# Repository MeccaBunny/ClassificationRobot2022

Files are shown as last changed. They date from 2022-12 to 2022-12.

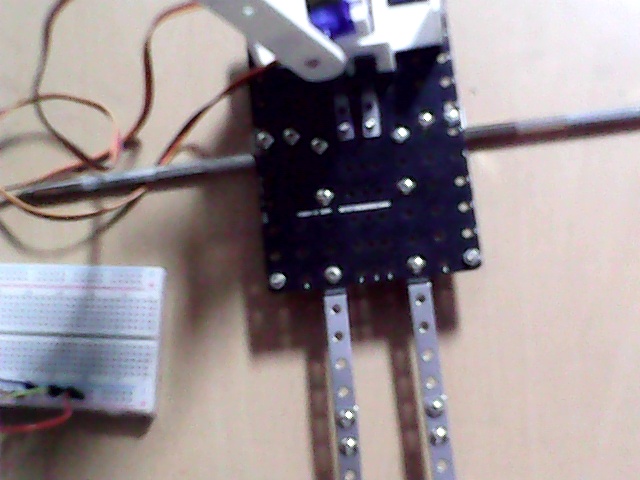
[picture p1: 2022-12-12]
robot_arm_controller/photo.jpg

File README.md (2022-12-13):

## ClassificationRobot2022

Uploaded files are located at /home/meccabunny/robot_ws/src/robot_arm_controller/robot_arm_controller/

Also yolov3.weights should be added to that directory too.

link to download yolov3.weights: https://pjreddie.com/darknet/yolo/

The environment I used to develop this robot is ubuntu 22.04. and the Open-source-software I used is ROS-humble, yolov3, opencv 4.6.0.

"robotParts" contains the stl file I used to 3d print this robot arm.

"robotArm" contains the arduino file for robot arm. <br/> <br/>

To Activate a robot,

First, Turn on 6 terminals in ubuntu. <br/> <br/>

Second, turn on arduino ise and upload the file given in robotArm.

$ arduino

Uploading the code directly will cause an error.

The reason for this error is because usb port connected to arduino cable is not authorized.

Copy and paste this command in 2nd terminal.

$ sudo chmod a+rw /dev/ttyACM0 <br/> <br/>

Third, for each terminal, turn on the ROS nodes to activate the robot arm.

To do this, copy and paste this commands to 3rd, 4th, 5th terminal.

$ ros2 run robot_arm_controller actionBuf

$ ros2 run robot_arm_controller inverse_kinematics

$ ros2 run robot_arm_controller CameraToUV  <br/> <br/>

Finally, copy and paste this command to 6th terminal.

$ cs

$ code .

Meaning of this code is that you are turning on vscode in directory "~/robot_ws/src/".

Then, run the python code, "ObjectDetectionCamera.py"

<br/>

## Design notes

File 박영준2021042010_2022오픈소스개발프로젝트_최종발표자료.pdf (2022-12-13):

# 산업용 분류로봇

## 2022오픈소스개발프로젝트

### 박영준2021042010

목차

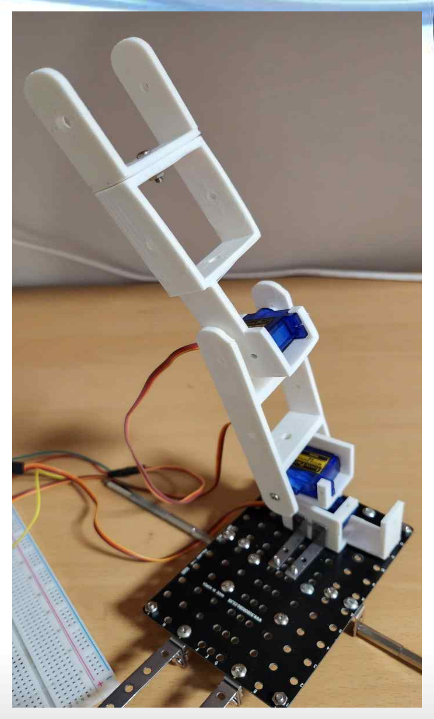
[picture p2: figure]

## - 1. 과제 제목 & 개요

## - 2. 과제 필요성

## - 3. 개발 목표

## - 4. 프로젝트 설계

## - 5. 개발 일정 & 실적

## - 6. 프로젝트 결과

## - 7. 소감 및 후속 연구 계획

# 1. 과제 제목 & 개요

# 과제명: 분류 로봇

## 산업환경에서 공장 자동화에 필수적인 분류로봇을 구현한다. 분류로봇은 카메라를 이용하여 불량한 제품을 파악하고, 로봇팔을 이용

하여 불량한 제품을 컨베이어벨트에서 제거한다. 이 프로젝트의 최종목표는 분류로봇의 시제품을 제작하는 것이다.

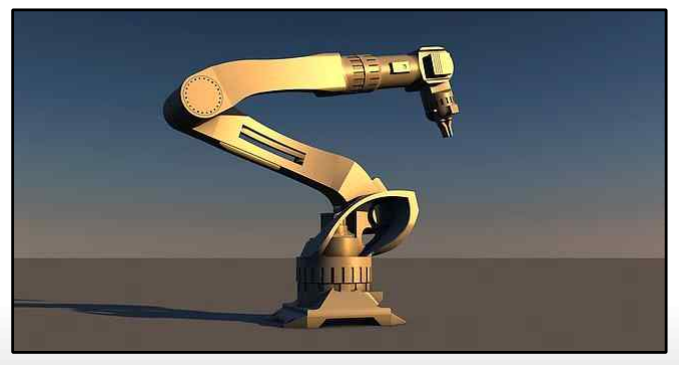
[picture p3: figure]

# 2. 과제 필요성

# 고령화시대

### - 우리나라는 현재 인구는 감소하고 있

### 지만, 고령자의 비중은 급속히 늘어나는

### 초고령사회에 들어섰다. 이러한 위기에서

### 우리나라가 그 미래를 대비하기 위헤서는

### 무인공장(스마트펙토리)을 도입하는 것은

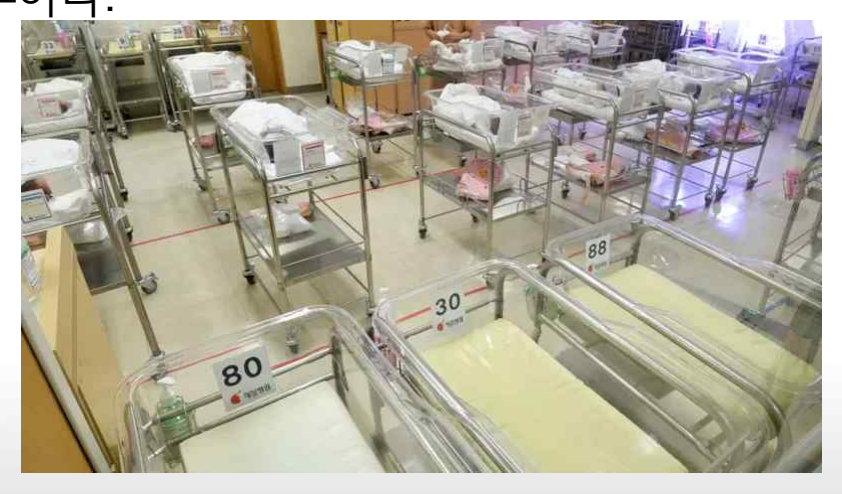
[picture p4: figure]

필수이다.

# 저렴한 로봇팔의 필요성

### - 인공지능 기술의 발달로 인하여 인간의 삶

### 의 많은 것을 자동화하는 기술이 연구되고 있

### 다. 이로 인하여 고등 정보기술 교육의 중요성

### 이 점점 높아지고 있다. 로봇을 조작하는 실습

### 으로 활용하기 좋은 기계들은, 교육에서 활용

하기에는 비싼 경우가 많다.

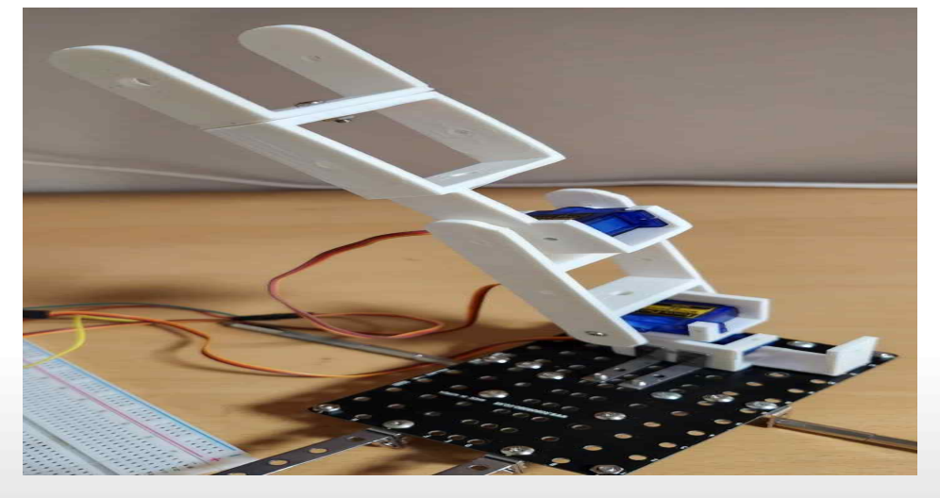
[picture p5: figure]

# 3. 개발 목표

-5000원 이하로 구현 가능한 다목적 로봇팔.

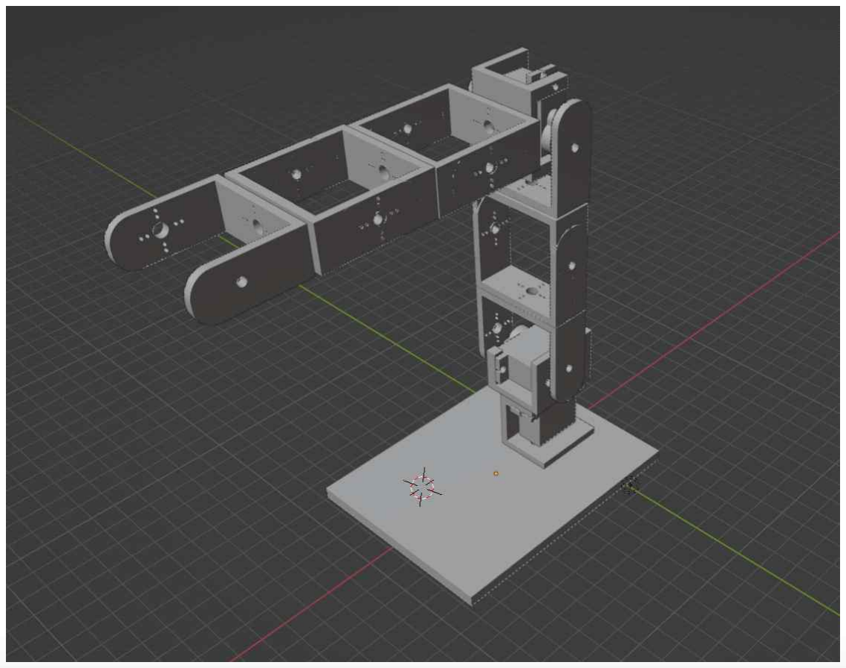
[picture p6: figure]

-YOLO를 활용한 객체인지 실습.

### -역기구학을 구현하여 로봇의 손 부분의

### X, Y, Z를 입력으로 로봇팔을 제어

# 4. 프로젝트 설계

### Classify goods using YOLO

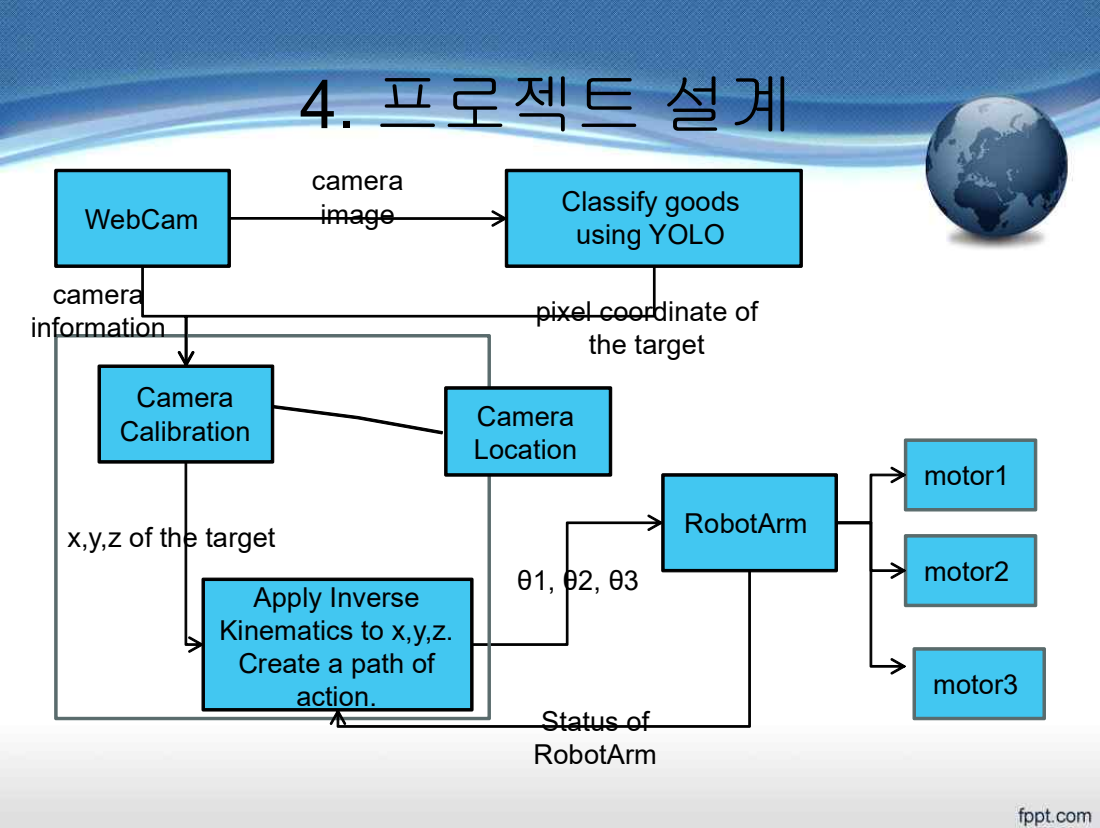
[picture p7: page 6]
WebCam; camera image; Camera Calibration; x,y,z of the target; RobotArm; motor1 motor2; Status of RobotArm; camera; information; Camera; Location; motor3

pixel coordinate of
the target

Apply Inverse Kinematics to x,y,z. Create a path of action.

# 4. 프로젝트 설계

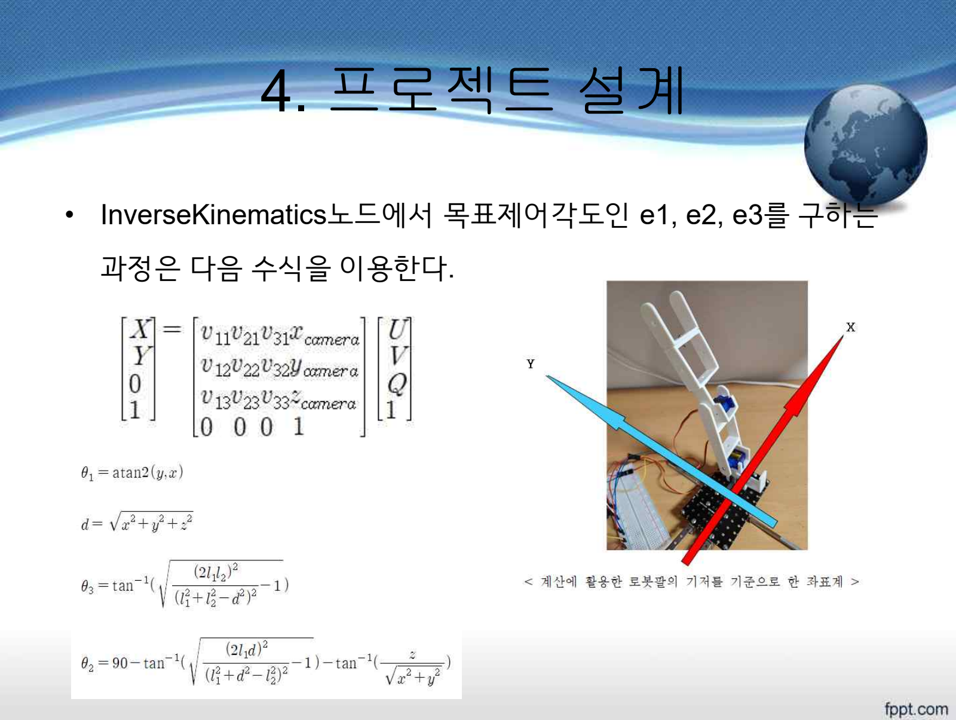
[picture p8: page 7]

## - InverseKinematics노드에서 목표제어각도인 e1, e2, e3를 구하는

과정은 다음 수식을 이용한다.

# 5. 개발 일정 & 실적

# - 1차 중간 발표까지 하드웨어를 제작. 웹캠을

보고 인간이 로봇팔을 조종하는 단계까지 제작.

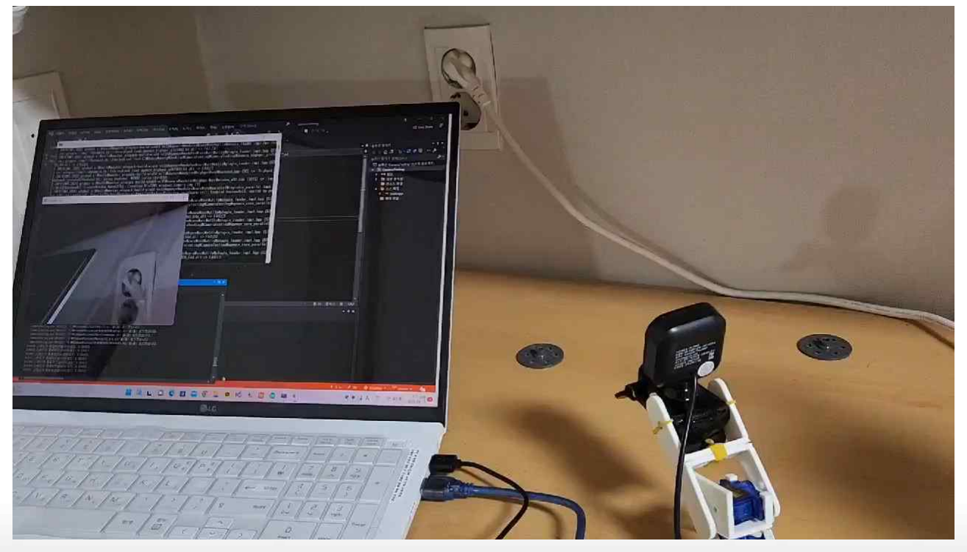
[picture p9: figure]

# 5. 개발 일정 & 실적

# - 2차 중간 발표까지 카메라와 로봇팔이 움직이는

부분에 대해서 최종제작을 하여 시제품을 발표.

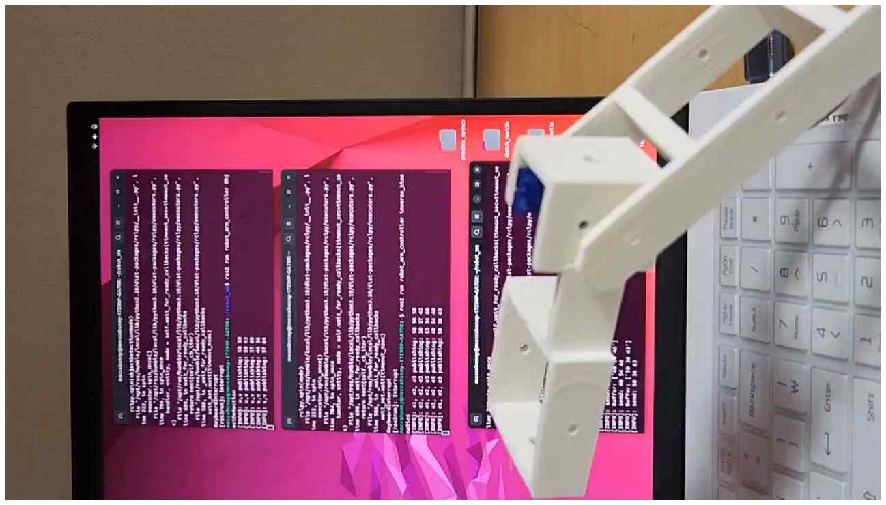
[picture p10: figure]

# 6. 프로젝트 최종 결과

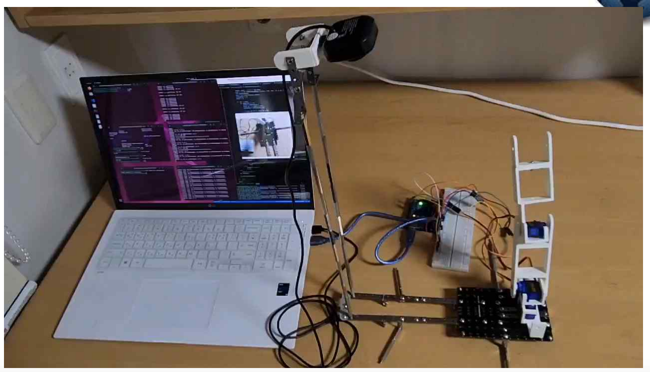
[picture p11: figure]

# 6. 프로젝트 최종 결과

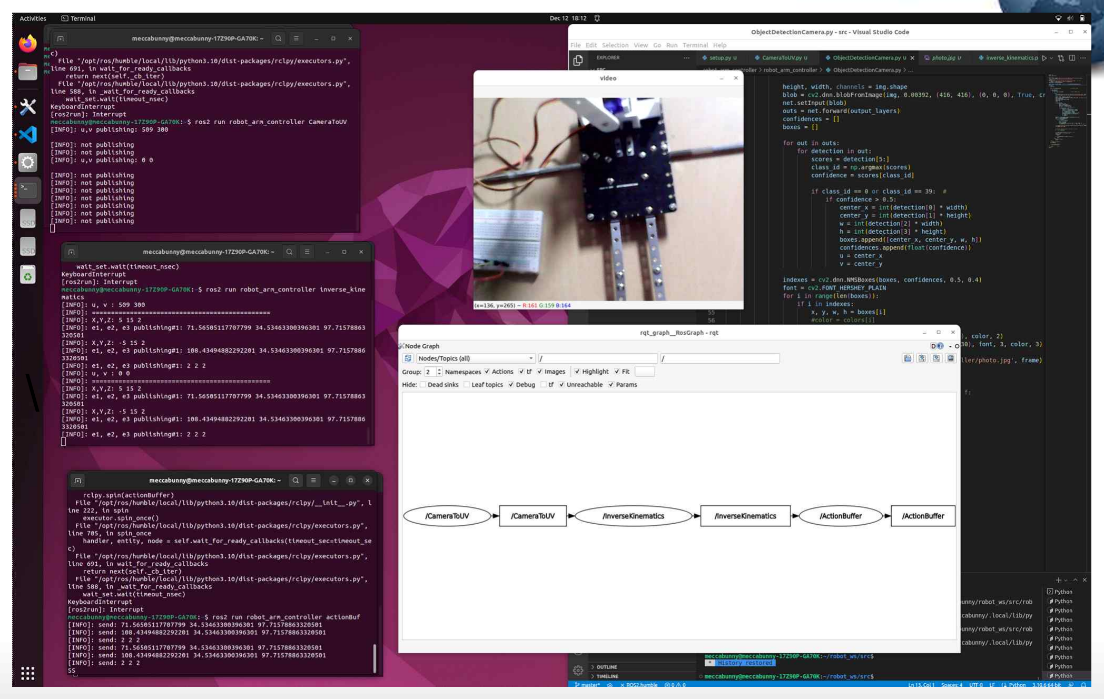
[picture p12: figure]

- \

# 6. 프로젝트 최종 결과

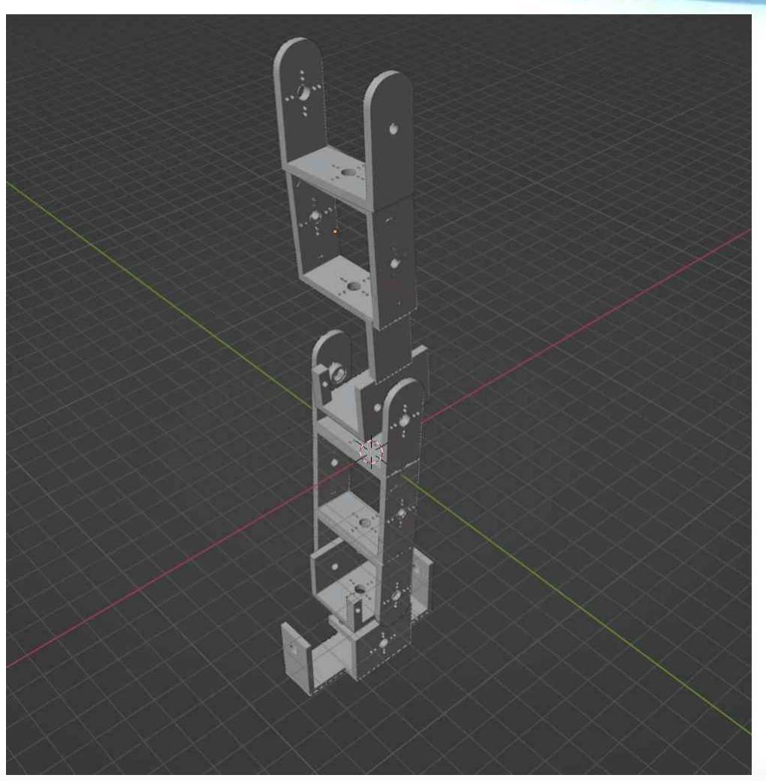
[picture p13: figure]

# 7. 소감 및 후속연구 계획

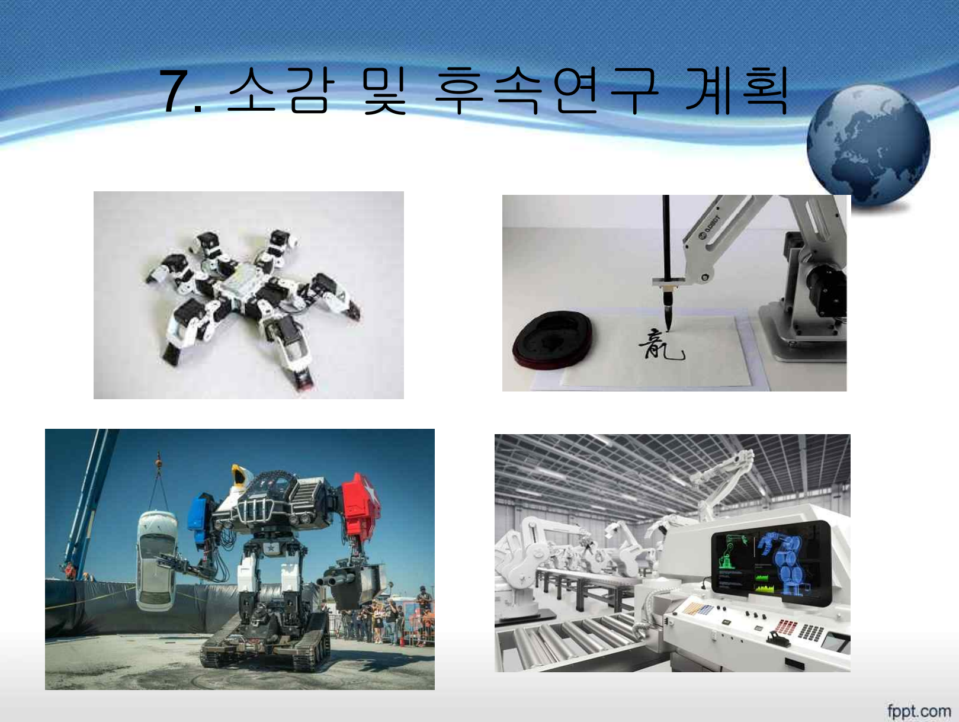
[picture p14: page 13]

# 참고자료

Ÿ과제의 필요성(초고령사회): https://www.bbc.com/korean/news-54506949

ŸSG-90 모터 브라켓 STL:https://cults3d.com/en

ŸROS-humble: https://docs.ros.org/en/humble/Installation/Ubuntu-Install-Debians.html

ŸOpenCV: https://docs.opencv.org/4.x/d9/df8/tutorial_root.html

Ÿhttps://pysource.com/2019/06/27/yolo-object-detection-using-opencv-with-python/

Ÿ표윤석, 임태훈. 『ROS 2로 시작하는 로봇 프로그래밍』. 루비페이퍼, 2021. ŸJohn J. Craig. 『Introdution to Robotics Mechanics and control』. 3

rdEdtion . Pearson Prentice Hail, 2005. Ÿ허경용. 『아두이노 Arduino 상상을 스케치하다』. 제이펍, 2014.

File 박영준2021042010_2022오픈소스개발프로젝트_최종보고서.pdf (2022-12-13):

과목명:
담당교수:
학과:
학년:
학번:
이름:

20223오픈소스개발프로젝트
기석철
지능로봇공학과
2학년
2021042010
박영준

# 20223오픈소스 개발 프로젝트

# 최종보고서

### 20223 OpenSW Development Project Final Report

목 차

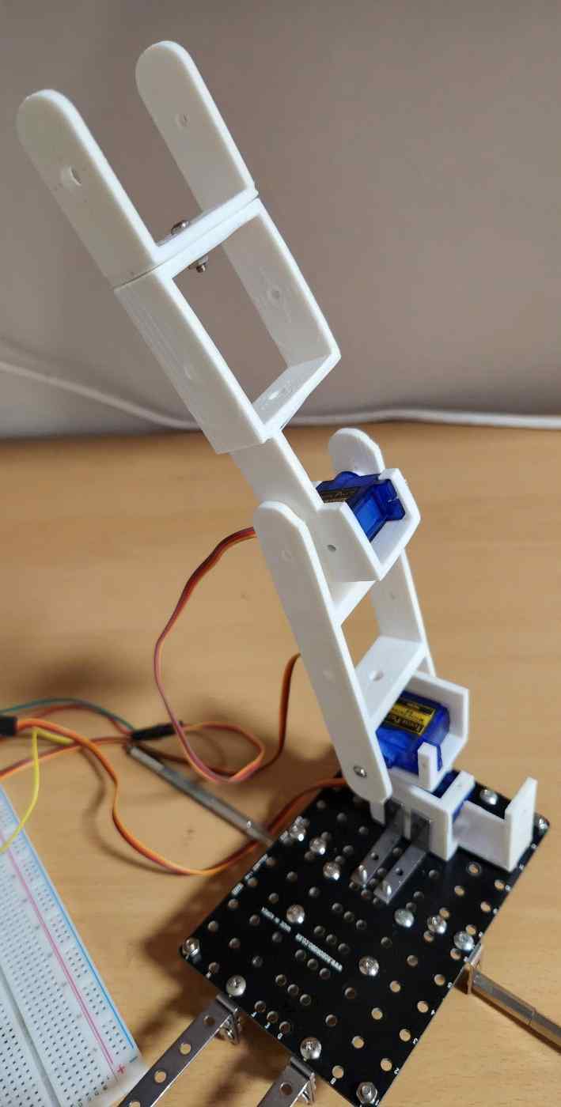
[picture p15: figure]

1. 과제 제목 & 개요
2. 과제 필요성
3. 개발 목표
4. 프로젝트 설계
-하드웨어 설계
-개발환경
-ROS 노드 연결 관계
5. 개발 일정 & 실적
-개발 일정
-1차 중간 발표
-2차 중간 발표
6. 프로젝트 결과
-최종 결과물
7. 소감 및 후속 연구 계획
-소감
-후속 연구 계획

# 산업용 분류 로봇

### Classification Robot

박영준
Park Youngjune

### 2. 과제 필요성

무인공장은 우리나라에 필수적이다. 우리나라는 현재 인구는 감소하고 있지만, 고령자의 비중은 급속히 늘어나는 초고령사회에

들어섰다. 내국인의 생산연령인구(15~64세) 구

성비는 2020년 71.5%에서 2040년 55.6%로 감

소할 것으로 보인다. 또한 미국의 계속되는 금리

인상에 의한 파장으로 물가가 치솟으면서 기업의

비용 부담이 늘어나고 소비자의 소비력이 구매력

이 감소하는 가운데 이미 경제는 여러 도전에 직

면해 있는 상황이다. 이러한 위기에서 우리나라

의 제조업이 취할 수 있는 선택지 중에는 무인공

장을 도입함으로써 인건비를 줄이는 방법이 있

다. 앞으로 미래에는 지금보다 더한 경제적인 위

기가 아주 많이 있을 것이다. 우리나라가 그 미

래를 대비하고 피해를 최소화하기 위해서는 무인

공장을 도입하는 것은 기업에 필수적이다. 저렴하게 제작 가능한 로봇팔이 필요하다. 인공지능 기술의 발달로 인하여 인간의 삶

의 많은 것을 자동화하는 기술이 연구되고 있다. 이로 인하여 고등 정보기술 교육의 중요성이 점

점 높아지고 있다. 정보기술을 이용하여 로봇을

조작하는 실습으로 활용하기 좋은 기계에는, RC

자동차, 로봇팔, 드론 등등이 있다. 그러나 이러

한 기계들은 교육에서 활용하기에는 비싼 경우가

많다. 고등 및 대학 교육에서 개인이 각각 로봇

팔을 이용한 실습을 진행하기 위해서는 로봇팔의

가격이 아주 저렴해질 필요가 있다.

### 1. 과제 제목 & 과제 개요

이 프로젝트는 산업 환경에서 공장 자동화

에 필수적인 분류 로봇을 구현하는 것을 목표로

한다. 분류 로봇이란, 센서를 통해서 양호한 제품

과 불량한 제품을 구별하고, 둘을 분류하는 작업

을 하는 로봇을 의미한다. 이 프로젝트는 카메라

의 센서 정보를 바탕으로 페트병 중에서 불량한

제품을 분별하여, 3 자유도의 로봇팔을 이용하여

불량한 제품을 컨베이어벨트에서 밀어내는 작업

을 수행하는 로봇을 구현할 것이다. 이 프로젝트

를 진행하는 과정에서 오픈소스(ROS, OpenCV,

등등)를 최대한 활용하므로 오픈소스를 활용하는

능력을 기를 것이다. 또한 로봇팔을 3d 프린터로

제작하기 위한 도면을 제작하면서 3d 프린터를

활용하여 원하는 형태의 기계 부품을 만드는 방

법을 배울 것이다.

## 3. 개발 목표

-5000원 이하의 다목적 로봇팔.

-YOLO를 활용한 객체인지 실습.

-역기구학을 구현하여 로봇의 손 부분의

X, Y, Z를 입력으로 로봇팔을 제어

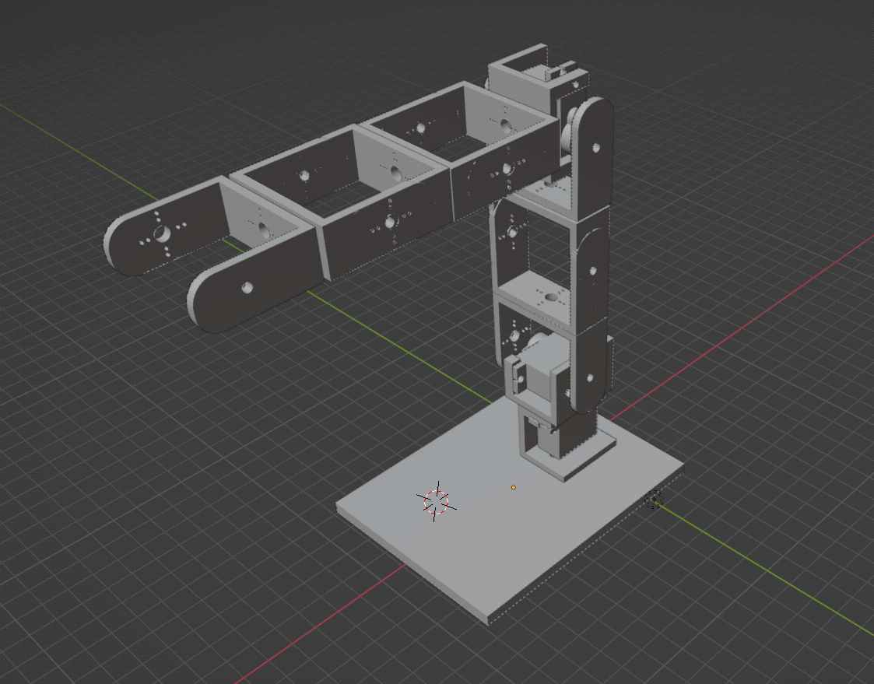
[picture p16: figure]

## 4. 프로젝트 설계

-하드웨어 설계
프로젝트에 사용할 로봇팔의 하드웨어 설계 목표는 로봇팔의 기능을 하는 가장 간단한 형태의 구조 를 만드는 것과 동시에, 다목적으로 사용될 수 있도록 하는 것이었다. 이를 위해서 나는 로봇팔의 핵심적인 부품인 모터를 고정하는 브라켓을 설계의 토대로 삼았다. 브라켓과 브라켓을 연결하는 연 결부위를 제외한 부분들은 최소화하였다. 로봇팔의 손 부분은 로봇팔의 목적에 따라서 집게를 장착 할 수도 있고, 그저 밀쳐내는 행동만 수행할 경우는 빗자루와 같은 형태일 수도 있듯이 다양할 수 있다. 그러므로 나는 로봇의 손 부분에는 나사를 통해서 여러 가지 모듈을 장착할 수 있도록 로봇 팔의 손 부분을 설계하였다. -개발환경

내가 이 프로젝트에서 사용한 개발환경은 UBUNTU 22.04과 ROS-humble을 사용하였다. 이를 사 용한 이유는, 첫 번째로 최신 버전의 Ubuntu와 ROS가 이전의 버전과 어떤 차이가 있는지 알고 싶 었기 때문이다. 두 번째로는 현재 많은 ROS에 관한 자료들은 Ubuntu 16.04 또는 Ubuntu 18.04를 기준으로 삼고 있다. 하지만

-ROS 노드 연결 관계

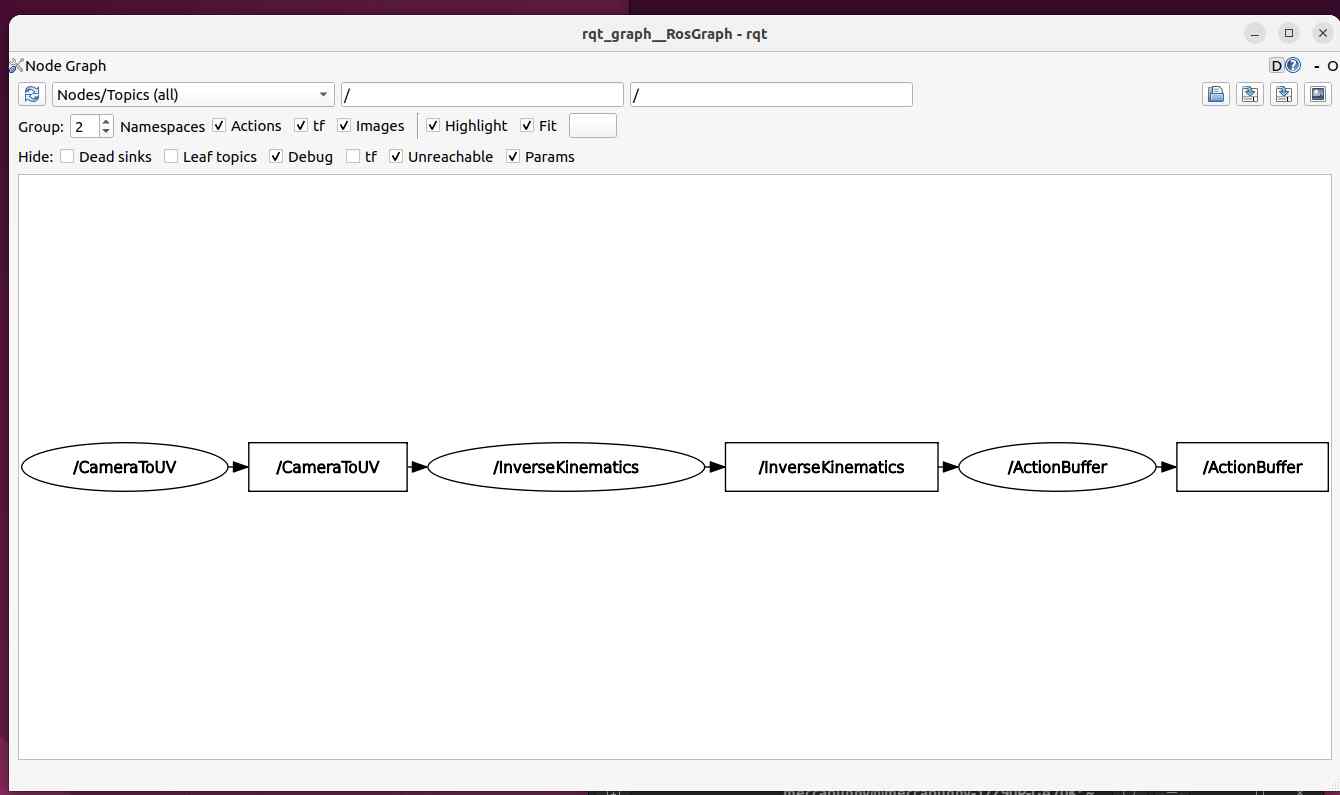
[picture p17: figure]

< rqt_graph를 사용하여 시각화한 노드의 연결 관계 >

ObjectDetectionCamera.py:
rqt_graph에는 보이지 않으나, 해당 파일을 작동시켜야 로봇이 카메라로부터 정보를 받을 수 있다. 이 파일은 카메라를 통해 YOLOv3를 이용한 객체 인식을 한다. 인지한 객체가 페트병일 경우에는

페트병의 위치 u, v를 uv.txt에 저장한다.

CameraToUV:
이 노드는 uv.txt로부터 페트병의 위치를 받아온다. 그리고 InverseKinematics 노드로 그 정보를 퍼 블리시한다.

InverseKinematics:
이 노드는 페트병의 위치, u v를 이용해서 물체의 위치 x,y,z를 계산한다. 그리고 얻어낸 물체의 위 치를 토대로 물체를 밀쳐내는 액션을 생성한다. 그 후, 액션에 해당되는 x,y,z를 역기구학을 이용해 서 모터의 목표 제어각도 e1, e2, e3를 구하고 ActionBuffer에 제어각도를 퍼블리시한다. ActionBuffer:

이 노드는 InverseKinematics로부터 얻은 액션에 대한 제어각도를 순차적으로 로봇팔을 제어하는 아두이노에 보내는 역할을 한다.

X

Y

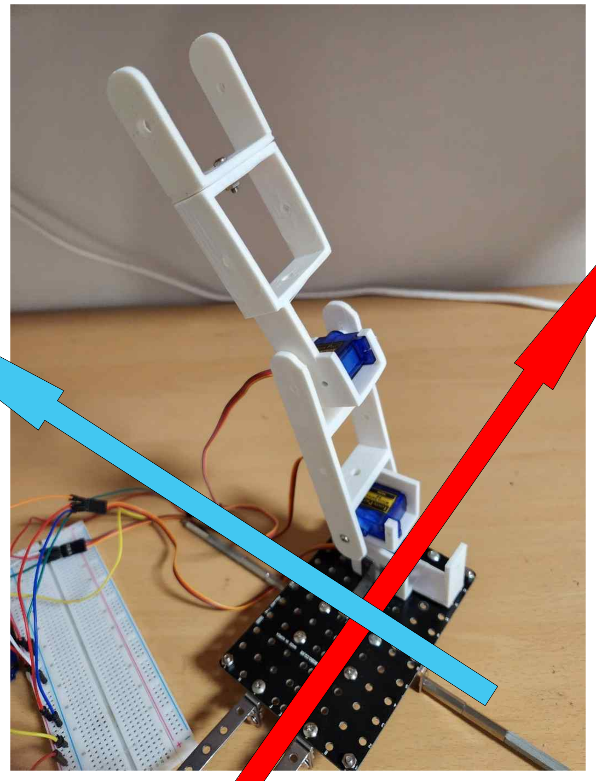
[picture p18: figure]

< 계산에 활용한 로봇팔의 기저를 기준으로한 좌표계 >

InverseKinematics노드에서 목표제어각도인 e1, e2, e3를 구하는 과정은 다음 수식을 이용한다.

이때 X, Y는 로봇팔에 대한 물체의 상대위치를 의미한다. 그리고 v1은 카메라의 u에 해당하는 벡 터, v2는 카메라의 v에 해당하는 벡터, v3는 q에 해당하는 벡터이다. U, V는 카메라에서 본 물체의 좌표를 의미한다. Q는 물체의 절대 좌표가 0이 되도록 하는 값이다. 위 방법을 통해서 물체의 로봇팔에 대한 상대위치를 알아냈다면, 이를 토대로 물체를 밀어내는 액

션을 생성한다. 액션은 로봇팔의 손을 (X+3, Y, 2)->(X-3, Y, 2)의 위치로 이동하는 것이다. 액션이 정해졌으므로 다음은 액션에 해당하는 좌표에 대응하는 모터의 제어 각도를 구해야 한다.

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

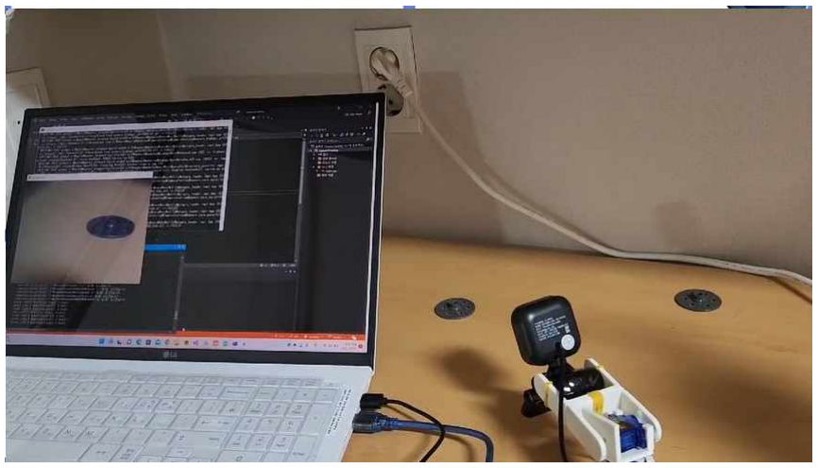
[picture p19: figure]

Cult3D 에서 SG-90 모터에 대한 브라켓의 stl 파일을 얻을 수 있었다. 나는 이 파일을 Blender를 이용하여 로봇팔에 맞게 수정하였다. 수정된 stl 파일은 충북대학교 메이커센터의 큐비콘 3d 프린터 를 이용하여 출력하였다. 그리고 Window 11 환경에서 OpenCV를 이용하여 카메라의 정보를 읽는 것을 구현하였다. -2차 중간 발표

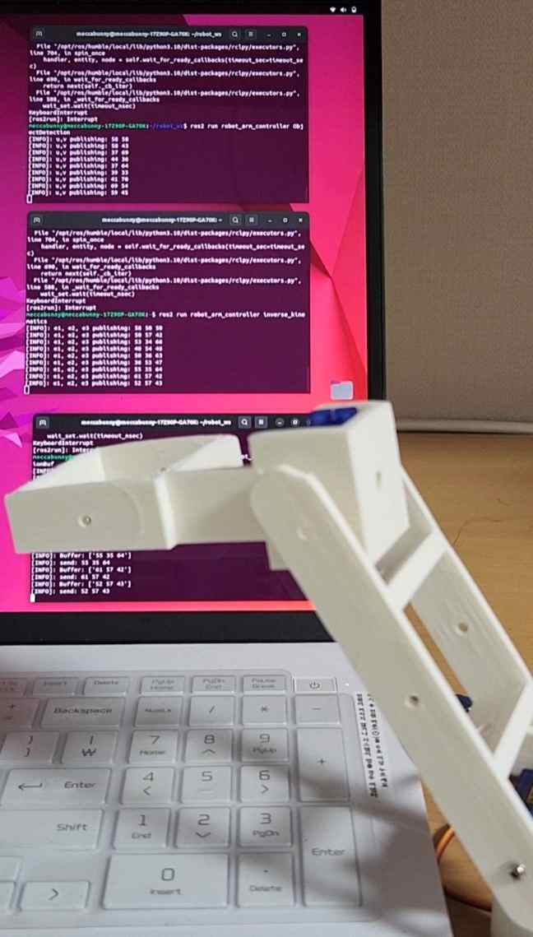
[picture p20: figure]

컴퓨터를 듀얼 부팅하여 Ubuntu 22.04를 설치하였다. 그리고 ROS-humble, OpenCV를 활용하기 위한 가상환경을 구축하였다. ROS 노드를 작성하여 카메라의 정보 u, v가 모터의 제어 각도로 변 환되는 정보 흐름을 구현하였다.

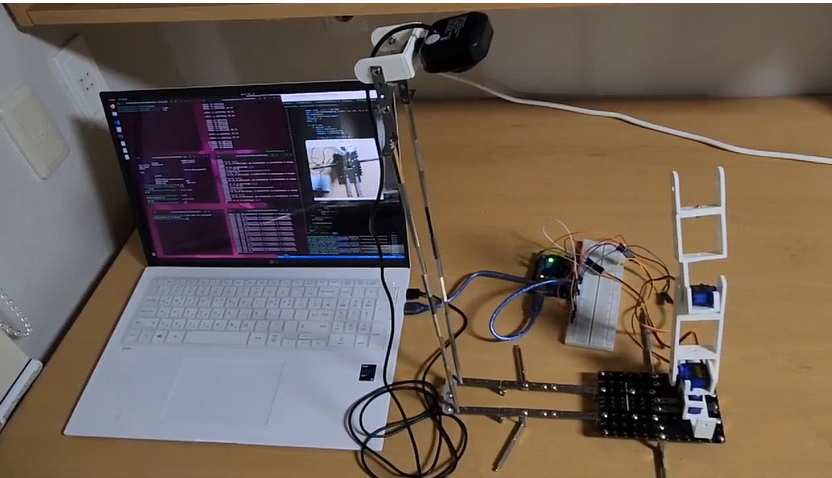
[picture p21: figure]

with open("/home/meccabunny/.ros/uv.txt", "r") as f:
u = f.readline()
v = f.readline()

## 6. 프로젝트 결과

github 링크:
https://github.com/MeccaBunny/ClassificationRobot2022

결과 시연 및 성능 평가

진행과정 및 문제점 해결
로봇팔의 모터를 아두이노로 제어하는 과정에서 정지해야 하는 모터가 무한히 회전하는 오류가 발 생하였다. 이 오류의 원인은 한 번에 여러 개의 모터를 제어하는 경우, 모터에 가하는 전력이 부족 할 떄 발생하는 오류였다. 이 문제를 해결하기 위해 나는 아두이노의 모터를 제어하는 코드를 수정 하여, 3개의 모터는 한 번에 하나씩만 순차적으로 움직이도록 하였다. 카메라에서 얻은 물체의 위치 정보 u, v를 노드에 전달하는 과정에서 나는 txt 파일에 u, v에 대한

정보를 쓰고, CameraToUV 노드에서 이 txt 파일을 읽음으로 정보를 전달하였다. 만일 이때 uv.txt 파일을 읽기 위해서는 절대 경로를 사용해야 한다. 또한 아래의 코드처럼 “~/.ros/” 위치에서 uv.txt 파일을 읽을 수 있다.

로봇의 기저가 무겁게 고정되어 있지 않으면, 로봇팔이 움직일 때, 기저와 기저에 고정된 카메라가 진동하는 문제가 발생하였다. 이를 해결하기 위해 나는 기저와 카메라를 고정하는 부분에 철심을 부착하여 흔들리지 않도록 고정하였다. 또한 기저와 카메라를 연결하는 부분을 3d 프린터를 사용하 여 제작하는 것은 비효율적이다. 대신에 기저를 고정하기 쉽도록 설계하는 것이 바람직하다. 나는 기저를 고정하기 위해서 해당 브라켓에 얇은 구멍을 뚫어 그 부분을 철로된 브라켓과 연결하였다.

## 7. 소감 및 후속 연구 계획

이 프로젝트를 통해서 나는 분류 로봇의 시제품을 만들어 보았다. 처음에 프로젝트를 선정하게 된

이유는 카메라와 로봇팔이 있으면, 다양한 이미지 처리, 인공지능, 기구학 등등의 로봇과 관련된 분야를

실습해 볼 수 있기 때문이었다. 그러나 시중에 판매되는 로봇팔은 나의 기대보다 비쌌고, 또한 특수한 목

적의 로봇팔들을 사용하기 위해서는 직접 로봇팔을 제작하는 방법을 알 필요가 있음을 느꼈다. 이 프로젝

트에서 로봇팔은 나의 이러한 고민을 해결하기 위해 최대한 저렴하게 목표의 동작을 수행할 수 있도록 설

계되었다. 이 보고서가 나와 같은 고민을 한 사람들에게 로봇팔을 제작하는 방법에 대한 가이드라인이 되

었으면 좋겠다. 내가 이 프로젝트를 진행한 이유는 앞으로 로봇을 공부할 때 실습으로 사용해보기 위함이었다. 따라

서 인공지능이라는 분야를 공부할 때, 카메라를 통한 인식의 결과 확인으로서 로봇에 액션을 가할 것이

다. 로봇팔은 전기 신호를 통해서 물리적인 출력을 가하는 아주 기초적인 도구이다. 후속 연구에서 나는

이 프로젝트를 진행하면서 얻은 경험을 토대로 여러 개의 로봇팔을 이용하여 시각 정보를 처리하여 보행

하는 보행 로봇을 만드는 것을 구현할 것이다. 참고 자료

Ÿ 과제의 필요성(초고령사회): https://www.bbc.com/korean/news-54506949
Ÿ SG-90 모터 브라켓 STL: https://cults3d.com/en
Ÿ ROS-humble: https://docs.ros.org/en/humble/Installation/Ubuntu-Install-Debians.html Ÿ OpenCV: https://docs.opencv.org/4.x/d9/df8/tutorial_root.html Ÿ https://pysource.com/2019/06/27/yolo-object-detection-using-opencv-with-python/ Ÿ 표윤석, 임태훈. 『ROS 2로 시작하는 로봇 프로그래밍』. 루비페이퍼, 2021. Ÿ John J. Craig. 『Introdution to Robotics Mechanics and control』. 3

rd Edtion . Pearson
Prentice Hail, 2005. Ÿ 허경용. 『아두이노 Arduino 상상을 스케치하다』. 제이펍, 2014.
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

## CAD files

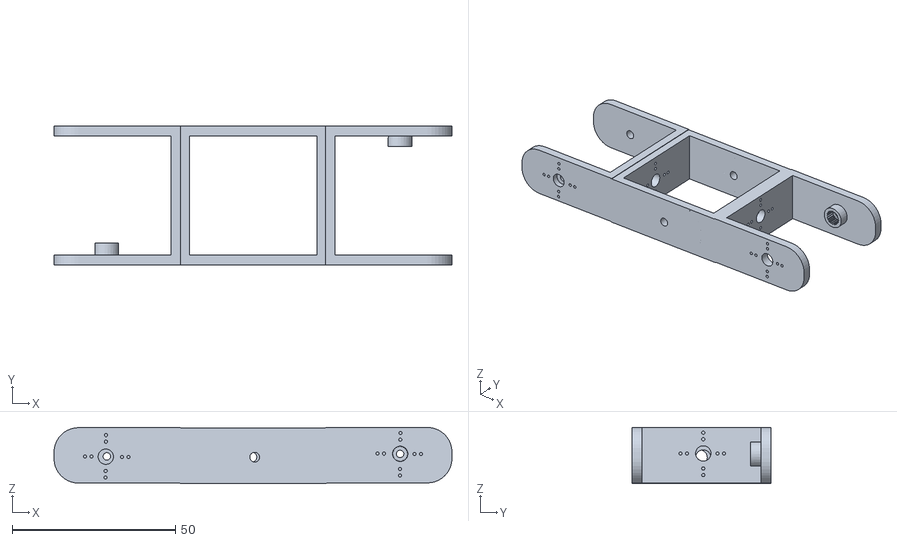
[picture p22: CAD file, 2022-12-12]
robotParts/Arm_L1.stl
121.8 x 42.6 x 17.2

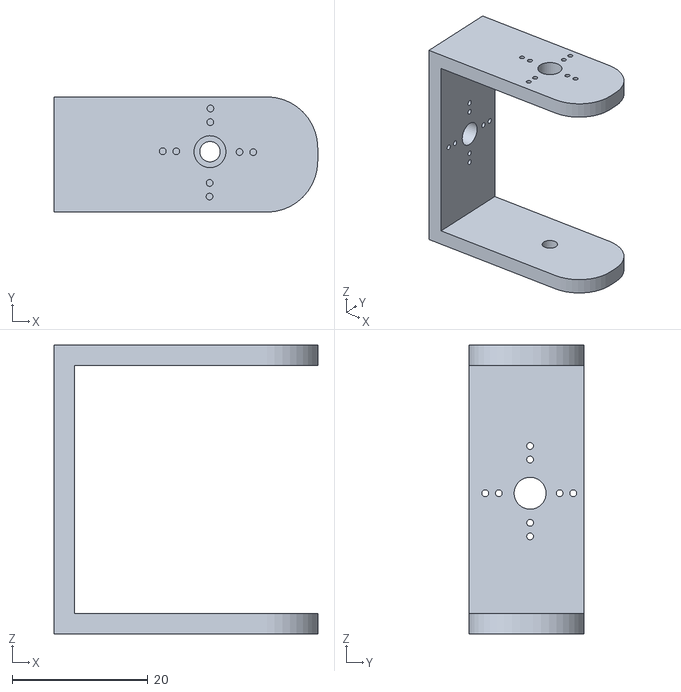
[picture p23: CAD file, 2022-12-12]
robotParts/Arm_Hand.STL
38.8 x 17.0 x 42.5

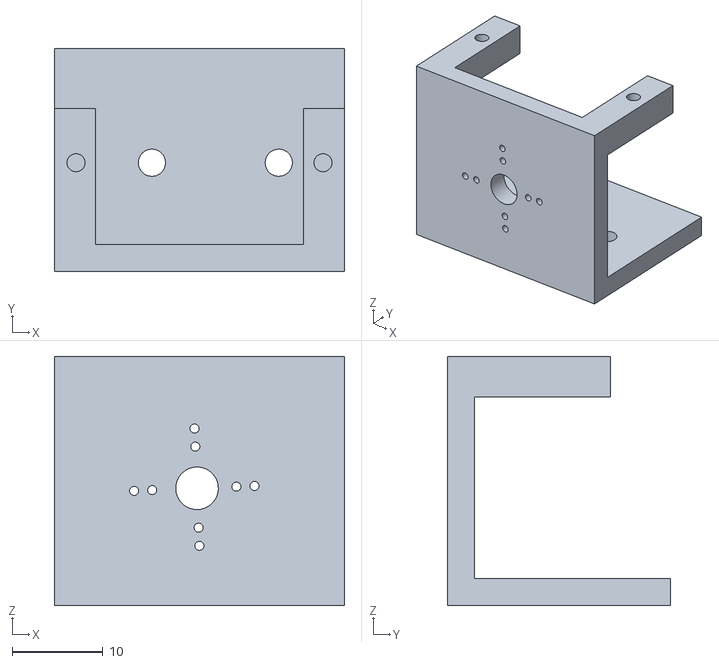
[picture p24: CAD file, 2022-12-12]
robotParts/Arm_body.STL
32.0 x 24.6 x 27.5

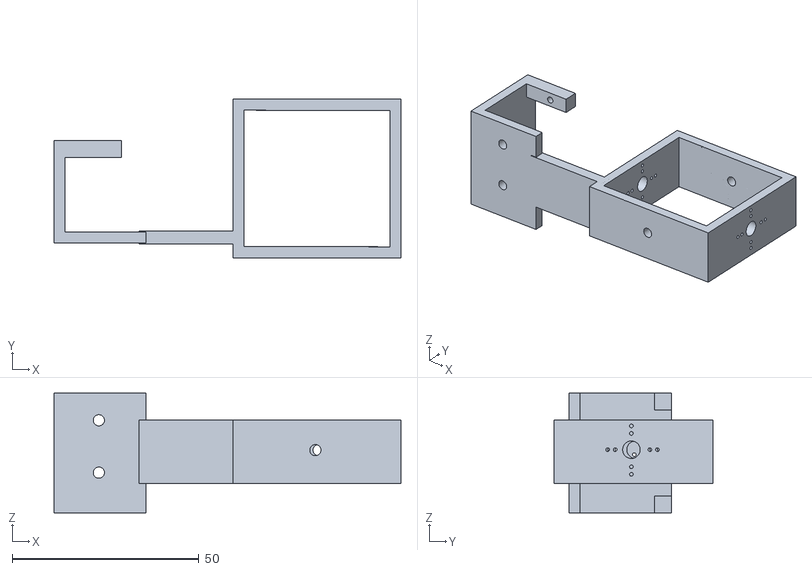
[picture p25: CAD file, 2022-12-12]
robotParts/Arm_L2.stl
92.8 x 42.5 x 32.0

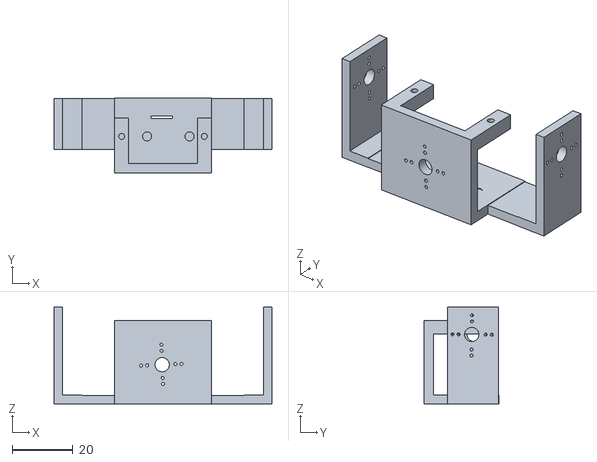
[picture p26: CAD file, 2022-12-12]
robotParts/Arm_Base.stl
71.9 x 24.6 x 32.0

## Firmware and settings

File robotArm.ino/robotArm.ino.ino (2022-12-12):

#include<Servo.h>

Servo servo1;
Servo servo2;
Servo servo3;

String msg = "";

String str_angles[3];

int angle1 = 0;
int angle2 = 0;
int angle3 = 0;

int angle_prev1 = 0;
int angle_prev2 = 0;
int angle_prev3 = 0;

int count = 0;
int tmpi = 0;

void setup()
{
  Serial.begin(9600);
  
  servo1.attach(9);
  servo2.attach(10);
  servo3.attach(6);

  for(int i = 0; i < 3; i++)
  {
    str_angles[i] = ""; 
  }
  
  servo1.write(0);
    delay(100);
  servo2.write(0);
    delay(100);
  servo3.write(0);  
    delay(100);
}


void loop()
{
  if(Serial.available())
  {
    msg = Serial.readString();
    
    Serial.println("received: " + msg);

    count = 0;
    tmpi = 0;
    for(int i = 0; i < msg.length()-1; i++)
    {
      if(msg[i] == ' ')
      {
        if(count == 0)
        {
          str_angles[0] = msg.substring(0, i);
          tmpi = i;
        }
        else if(count == 1)
        {
          str_angles[1] = msg.substring(tmpi+1, i);
          tmpi = i;
          str_angles[2] = msg.substring(i+1, msg.length()-1);
          break;
        }
        count += 1;
      }
    }

    angle_prev1 = angle1;
    angle1 = str_angles[0].toInt();

    angle_prev2 = angle2;
    angle2 = str_angles[1].toInt();

    angle_prev3 = angle3;
    angle3 = str_angles[2].toInt();

        servo1.write( (int) (angle_prev1 + 0.4 * (angle1 - angle_prev1)) );
        delay(150);
        servo2.write( (int) (angle_prev2 + 0.4 * (angle2 - angle_prev2)) );
        delay(150);
        servo3.write( (int) (angle_prev3 + 0.4 * (angle3 - angle_prev3)) );
        delay(150);
        servo1.write( (int) (angle_prev1 + 0.7 * (angle1 - angle_prev1)) );
        delay(150);
        servo2.write( (int) (angle_prev2 + 0.7 * (angle2 - angle_prev2)) );
        delay(150);
        servo3.write( (int) (angle_prev3 + 0.7 * (angle3 - angle_prev3)) );
        delay(150);
        servo1.write( (int) (angle_prev1 + 1.0 * (angle1 - angle_prev1)) );
        delay(150);
        servo2.write( (int) (angle_prev2 + 1.0 * (angle2 - angle_prev2)) );
        delay(150);
        servo3.write( (int) (angle_prev3 + 1.0 * (angle3 - angle_prev3)) );
        delay(150);
        
    //Serial.println((String)angle1+ "|" + (String)angle2 + "|"+ (String)angle3);
  }
  else
  {
    delay(500);
  }
  delay(10);
}

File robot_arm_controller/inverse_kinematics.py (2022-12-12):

#!/usr/bin/env python3
import rclpy

import rclpy
from rclpy.node import Node

from std_msgs.msg import String

import math

import time

import os

class InverseKinematicsNode(Node):
    def __init__(self):
        super().__init__("InverseKinematics")
        self.pub = self.create_publisher(String, "InverseKinematics", 10)
        #self.timer = self.create_timer(1.0, self.timer_callback)
        self.subscription = self.create_subscription(
            String,
            'CameraToUV',
            self.listener_callback,
            10)
        self.subscription

        self.l1 = 9
        self.l2 = 12

    def listener_callback(self, msg):
        uv = msg.data.split(" ")

        u = int(uv[0])
        v = int(uv[1])

        #with open("~/robot_ws/src/robot_arm_controller/robot_arm_controller/uv.txt", "r") as f:
        #    u = f.readline()
        #    v = f.readline()

        self.get_logger().info("u, v : {} {}".format(u, v))

        h = 0.01
        u *= h
        v *= h

        #x = u
        #y = v
        #z = 0

        x = 0
        y = 15
        z = 2

        x1 = x + 5
        y1 = y
        z1 = z

        x2 = x - 5
        y2 = y
        z2 = z

        self.get_logger().info("===============================================")
        self.get_logger().info("X,Y,Z: {} {} {}".format(x1, y1, z1))

        if( (pow(x1,2) + pow(y1,2) + pow(z1,2)) < (pow( self.l1 + self.l2, 2 )) and
        (pow(x2,2) + pow(y2,2) + pow(z2,2) < pow(self.l1 + self.l2 , 2))):

            e11,e12,e13 = XYZtoE123(self.l1, self.l2, x1, y1, z1)
            e1 = str(e11) + " "  + str(e12) + " " + str(e13)+ " "
            msg.data = e1
            self.pub.publish(msg)
            time.sleep(0.1)
            self.get_logger().info("e1, e2, e3 publishing#1: %s " % msg.data)

            self.get_logger().info("X,Y,Z: {} {} {}".format(x2, y2, z2))

            e21,e22,e23 = XYZtoE123(self.l1, self.l2, x2, y2, z2)
            e2 = str(e21) + " "  + str(e22) + " " + str(e23)+ " "
            msg.data = e2
            self.pub.publish(msg)
            time.sleep(0.1)
            self.get_logger().info("e1, e2, e3 publishing#1: %s " % msg.data)

            e31, e32, e33 = 2, 2, 2
            e3 = str(e31) + " "  + str(e32) + " " + str(e33)+ " "
            msg.data = e3
            self.pub.publish(msg)
            time.sleep(0.1)
            self.get_logger().info("e1, e2, e3 publishing#1: %s " % msg.data)
        else:
            msg.data = "Action is out of robot's span."
            self.get_logger().info(" %s " % msg.data)

def XYZtoE123(l1,l2,x,y,z):
    e1 = math.atan2(y,x)
    e1 = e1 / math.pi * 180

    d = math.sqrt(pow(x,2)+pow(y,2)+pow(z,2))

    e3 = math.atan(  math.sqrt( (pow(2*l1*l2,2)-(pow((pow(l1,2)+pow(l2,2)-pow(d,2)),2)))  /  (pow((pow(l1,2)+pow(l2,2)-pow(d,2)),2))  )  )
    e3 = 180 - e3 / math.pi * 180

    k = math.atan(  math.sqrt(  (  pow(2 * l1 * d , 2) - pow( pow(l1,2) + pow (d, 2) - pow(l2, 2) , 2 ) ) / pow( pow(l1,2) + pow(d,2) - pow(l2, 2) , 2  )  )  )
    j = math.atan2(z, math.sqrt( pow(x,2) + pow(y,2) ) )
    k = k / math.pi * 180
    j = j / math.pi * 180
    e2  = 90 - k - j

    return e1,e2,e3

def main(args = None):
    rclpy.init(args=args)
    node = InverseKinematicsNode()
    rclpy.spin(node)
    rclpy.shutdown()


#        h = 0.01
#        u *= h
#        v *= h
#
#    #[X]      [   a1, a2, a3, xe  ]   [x]
#    #[Y]  =   [   b1, b2. b3, ye  ] * [y]
#    #[0]      [   c1, c2, c3, ze  ]   [Q]
#    #[1]      [   0,  0,  0,  1   ]   [1]
#
#        a1 = 1
#        b1 = 0
#        c1 = 0
#
#        a2 = 0
#        b2 = 1
#        c2 = 0
#
#        a3 = 0
#        b3 = 0
#        c3 = -1
#
#        xe = 0
#        ye = 12
#        ze = 0
#
#        Q = -(c1*u +c2*v + ze)/c3
#        X = a1*u + a2*v + a3+Q + xe
#        Y = b1*u + b2*v + b3*Q + ye
#
#        x = X
#        y = Y
#        z = 0
#
#        #action1
#        x1 = x
#        y1 = y - 3
#        z1 = 1
#        #action2
#        x2 = x
#        y2 = y + 3
#        z2 = 1
#        #action3
#        e31 = 0
#        e32 = 0
#        e33 = 0
#
